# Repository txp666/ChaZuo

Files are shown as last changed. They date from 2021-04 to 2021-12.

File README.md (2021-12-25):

# 智能插座2.0

半年前设计的智能插座，只完成一半，由于来了学校以后只能使用校园网，设备连接后需要登陆，所以一直没用这个插座，就扔墙角吃灰了。前几天想起来更新2.0。

## 1.  背景

Esp8266刷入HomeKit后，苹果手机可以在家庭APP中进行控制，但是如果没有ipad或homepod则只可以在局域网内使用，无法远程控制。

## 2.  解决方案

  使用两片esp8266，一片接入HomeKit一片接入阿里云。

## 3.  原理图

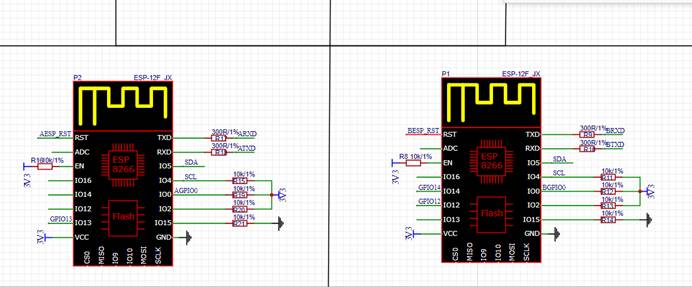
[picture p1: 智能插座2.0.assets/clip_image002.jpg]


两个芯片设置io4、io5进行软串口通讯

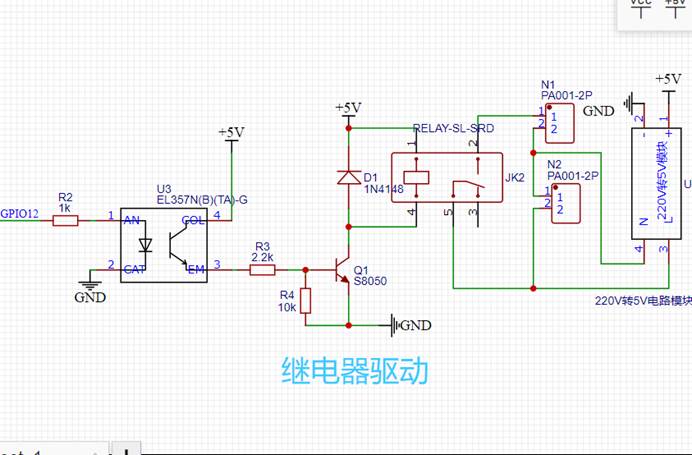
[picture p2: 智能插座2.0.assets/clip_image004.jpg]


Io12控制继电器

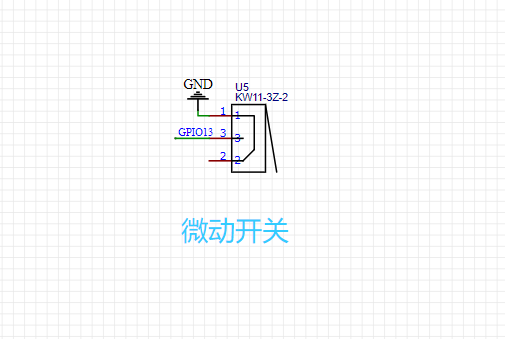
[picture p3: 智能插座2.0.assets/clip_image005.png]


Io13连接微动开关

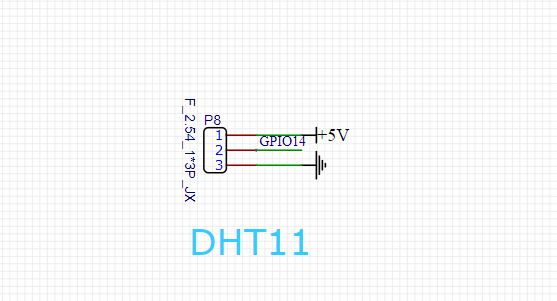
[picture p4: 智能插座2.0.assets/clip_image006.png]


可以添加温湿度传感器

## 4.  PCB

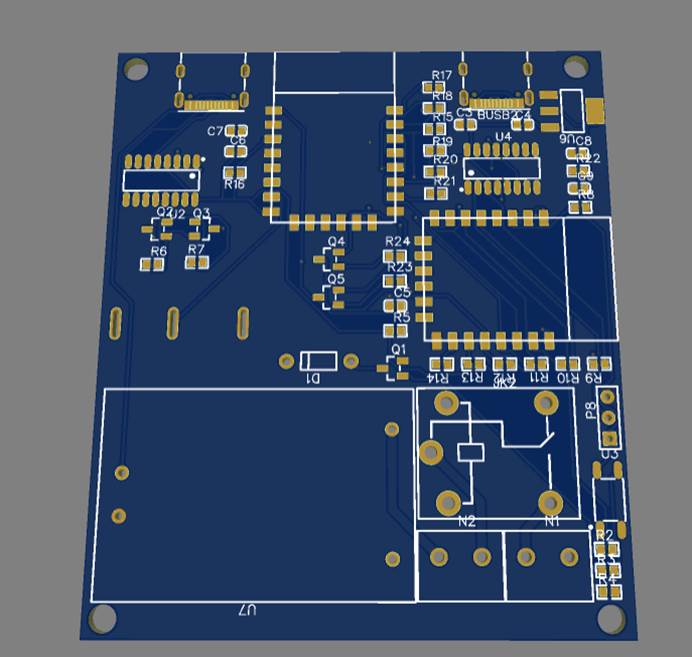
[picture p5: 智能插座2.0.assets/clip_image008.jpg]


使用了两个type-c接口分别对两个芯片下载程序

左边的刷阿里云的程序，右面的刷HomeKit。

## 5.  阿里云配置

进入阿里云物联网平台新建一个公共实例

https://iot.console.aliyun.com

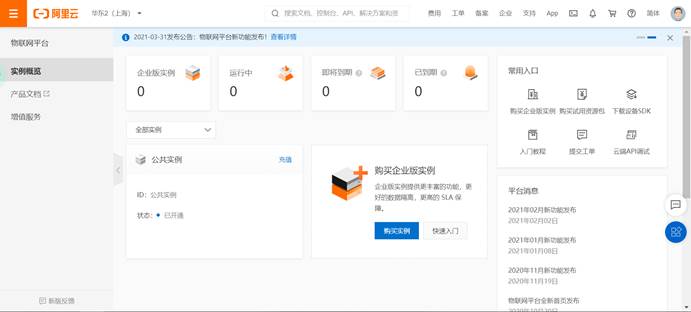
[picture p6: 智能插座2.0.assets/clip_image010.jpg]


创建一个产品

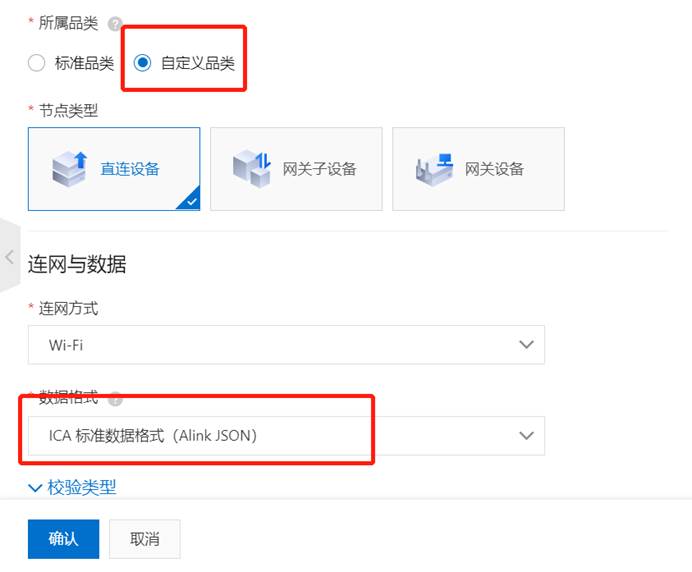
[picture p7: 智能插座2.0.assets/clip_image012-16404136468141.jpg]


添加一个设备

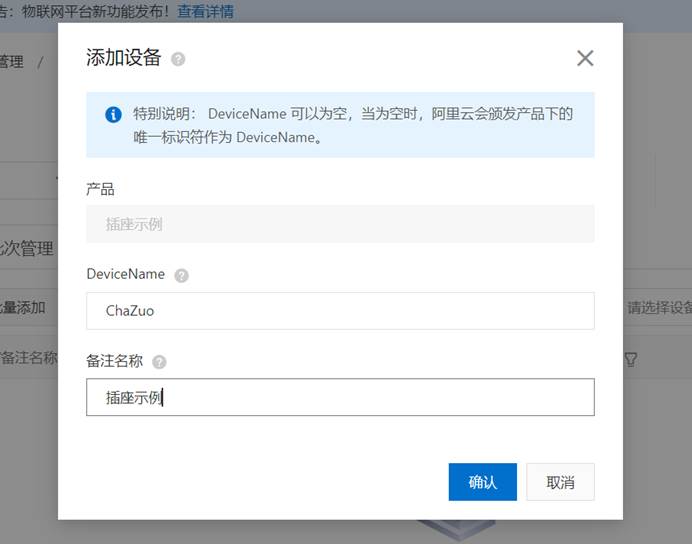
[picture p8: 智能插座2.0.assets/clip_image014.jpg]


回到产品，功能定义，编辑草稿

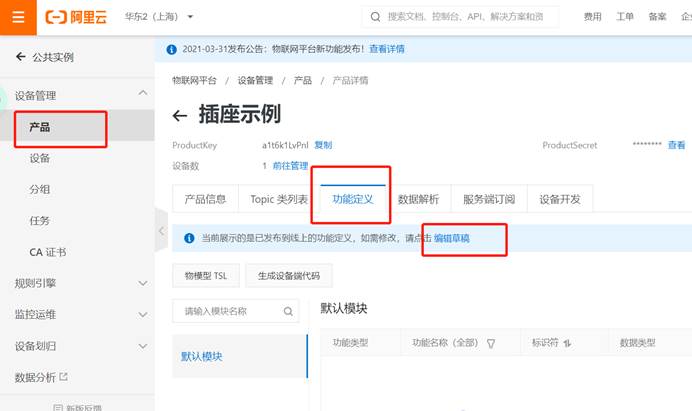
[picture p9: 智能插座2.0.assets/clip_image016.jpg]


添加一个自定义功能

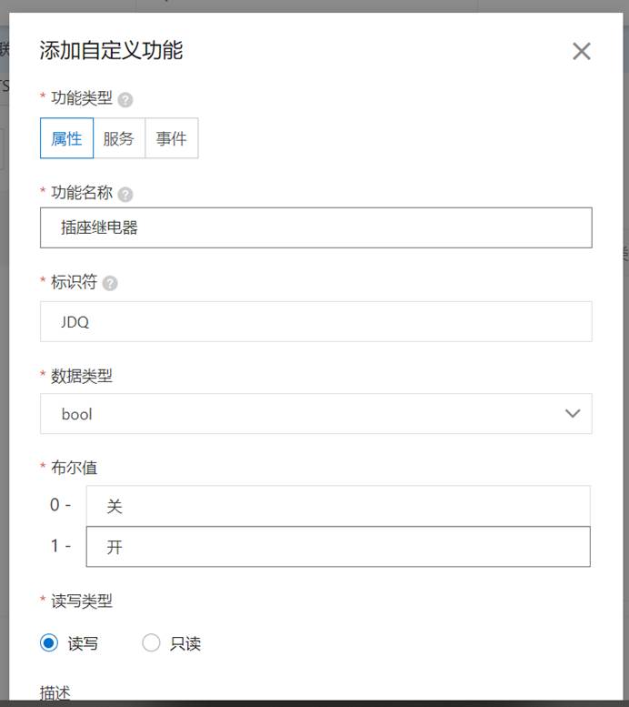
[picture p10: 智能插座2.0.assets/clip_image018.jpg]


发布上线

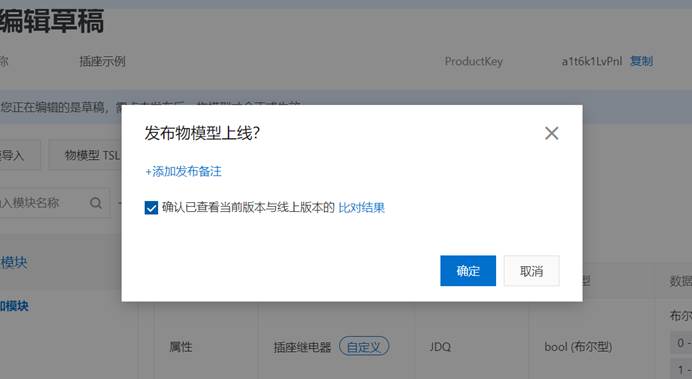
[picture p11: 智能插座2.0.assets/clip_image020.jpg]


## 6.  阿里云程序

这里用的Arduino环境写8266程序

环境搭建自行搜索

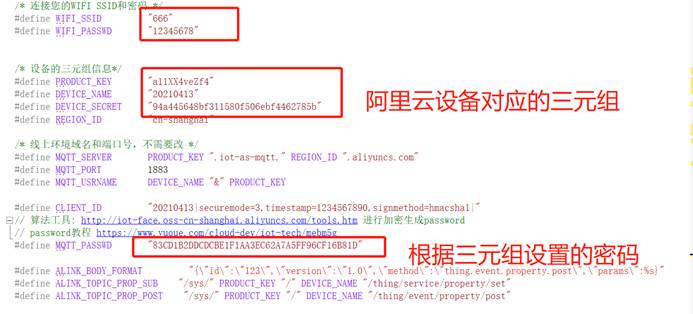
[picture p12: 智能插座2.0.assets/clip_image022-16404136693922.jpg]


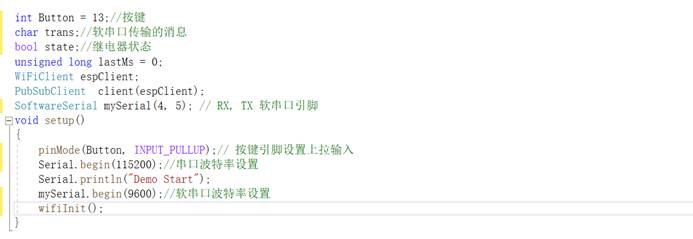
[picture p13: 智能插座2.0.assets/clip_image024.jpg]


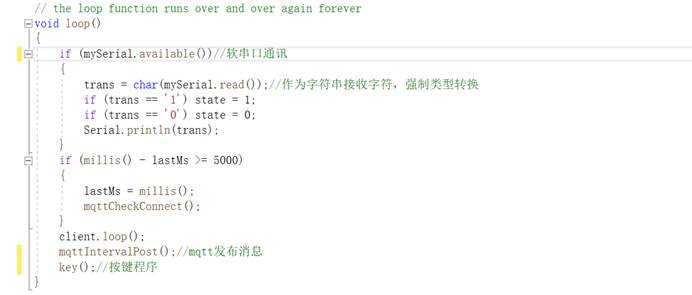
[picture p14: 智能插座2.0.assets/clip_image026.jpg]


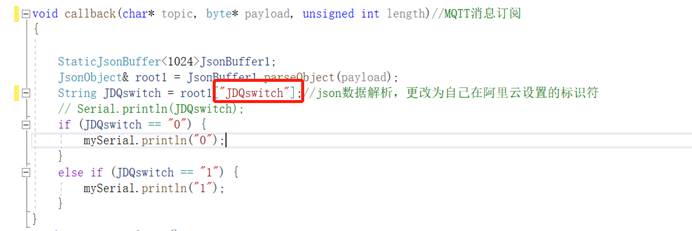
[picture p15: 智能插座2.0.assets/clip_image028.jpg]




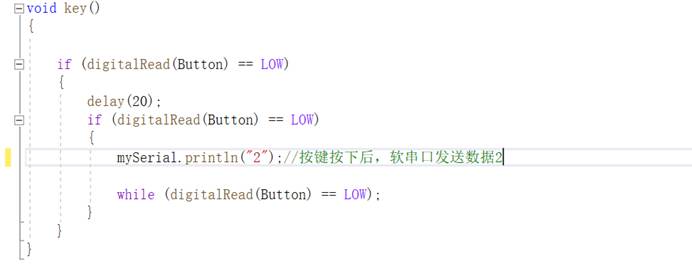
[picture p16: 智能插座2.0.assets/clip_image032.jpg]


## 7.  HomeKit程序

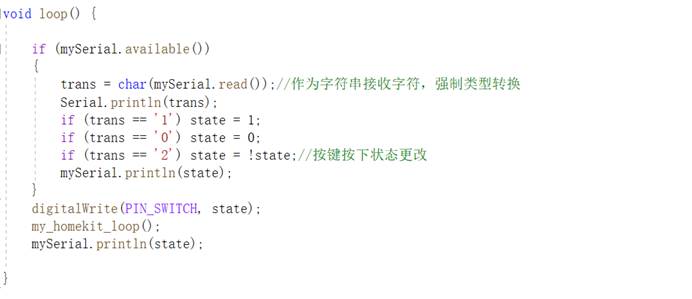
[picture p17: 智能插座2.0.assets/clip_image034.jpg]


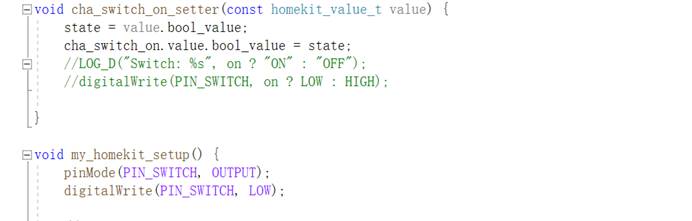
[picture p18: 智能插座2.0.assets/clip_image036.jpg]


特别注意一下，json库要使用V5版本

Pubsubclient.h也要修改

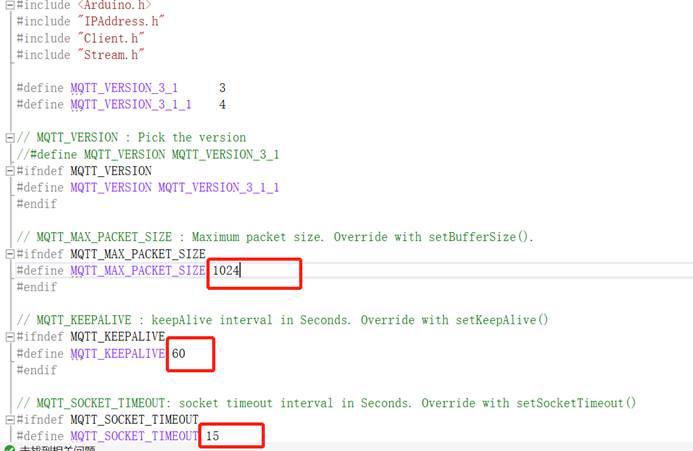
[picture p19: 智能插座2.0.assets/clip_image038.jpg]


## 8.  微信小程序

首先在新建的产品里新建一个设备，对应微信小程序

打开微信开发者工具，打开下载的程序（开发小程序，微信公众平台要进行设置，自行搜索）

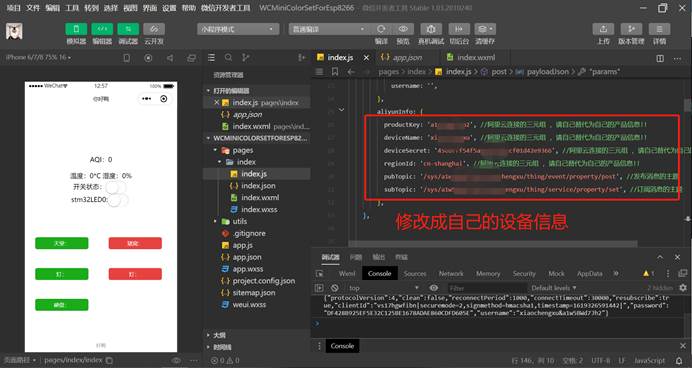
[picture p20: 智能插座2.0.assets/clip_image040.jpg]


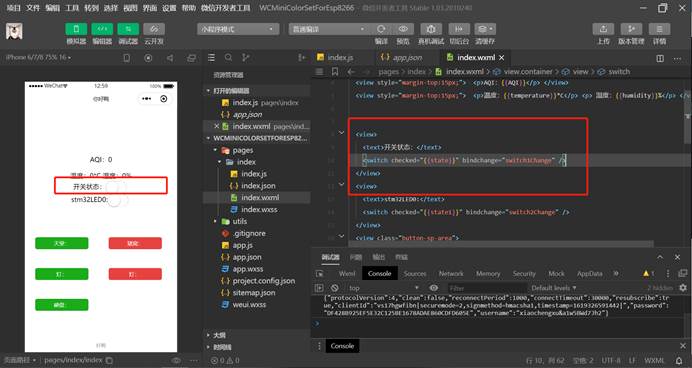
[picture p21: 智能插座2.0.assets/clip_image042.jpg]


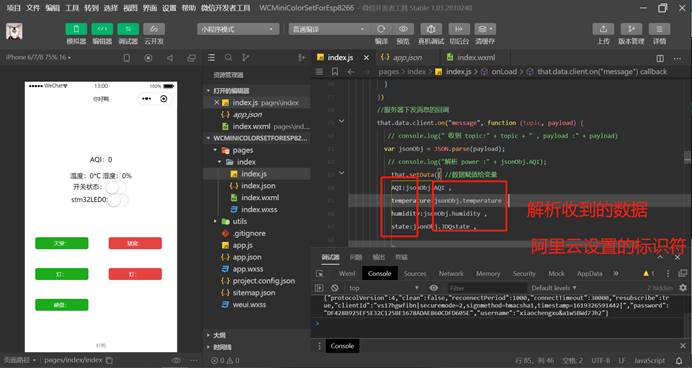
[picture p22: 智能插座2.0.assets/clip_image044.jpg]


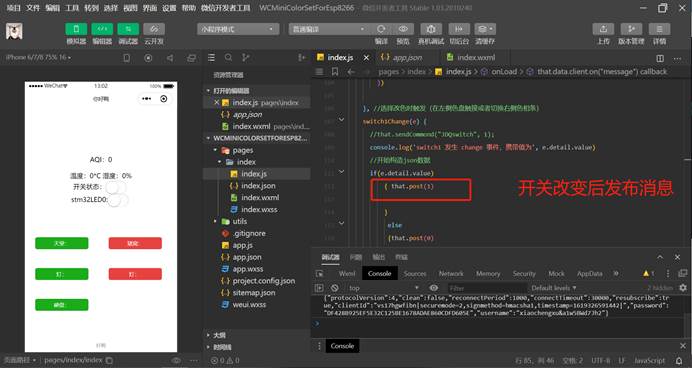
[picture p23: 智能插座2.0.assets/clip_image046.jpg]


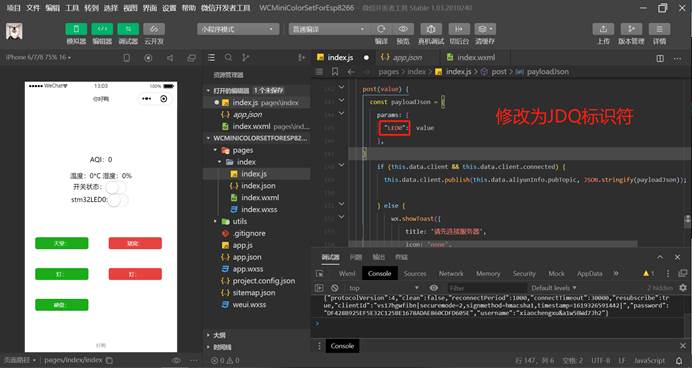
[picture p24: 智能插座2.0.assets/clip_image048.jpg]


阿里云设置数据流转，将小程序推送的消息转发到插座

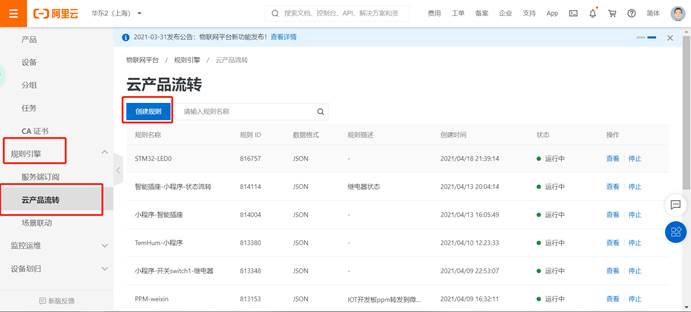
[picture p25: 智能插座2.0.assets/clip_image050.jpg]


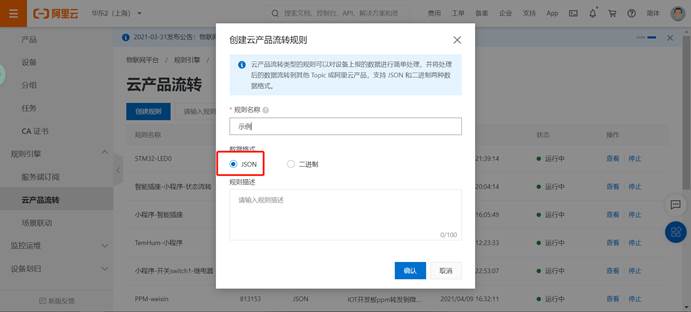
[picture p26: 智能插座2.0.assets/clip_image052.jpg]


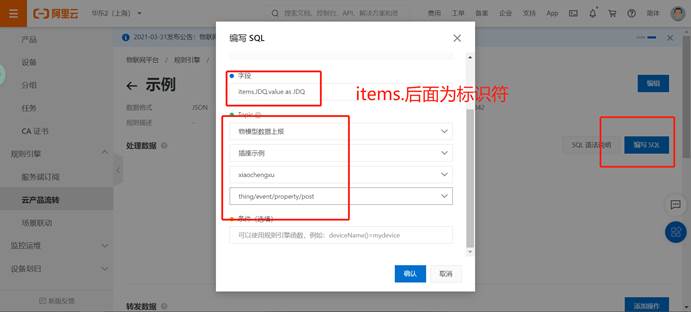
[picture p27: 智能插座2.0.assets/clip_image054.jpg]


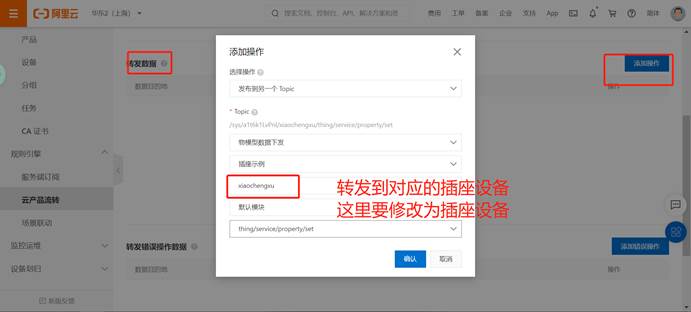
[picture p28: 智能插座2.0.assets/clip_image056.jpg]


返回去启动规则

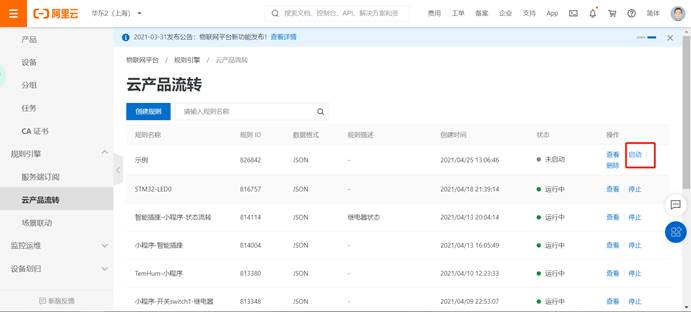
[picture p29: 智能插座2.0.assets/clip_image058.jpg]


完成后就可以使用小程序控制插座了，插座状态上传是一样的，建立规则把小程序状态流转到小程序

## 9.  HomeKit设置

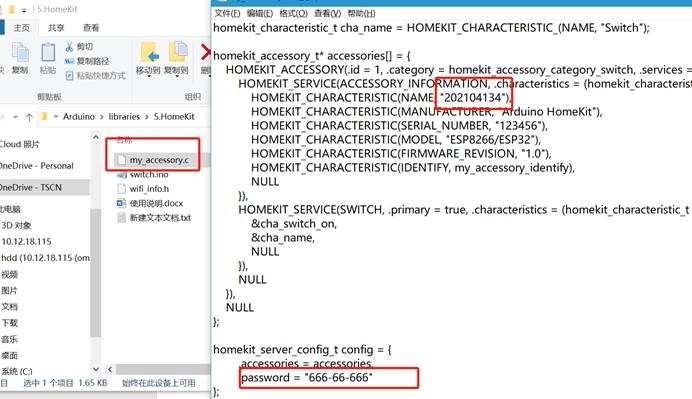
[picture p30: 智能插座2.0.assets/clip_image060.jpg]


名字时刷入flash ，所以如果在已经刷过homeKit程序的8266，需要清除flash信息（自行搜索）否则app里找不到设备

刷入程序后添加设备，点我没有或无法扫描，之后会弹出设备，输入上面设置的密码，之后按提示操作，HomeKit操作要在一个局域网内。

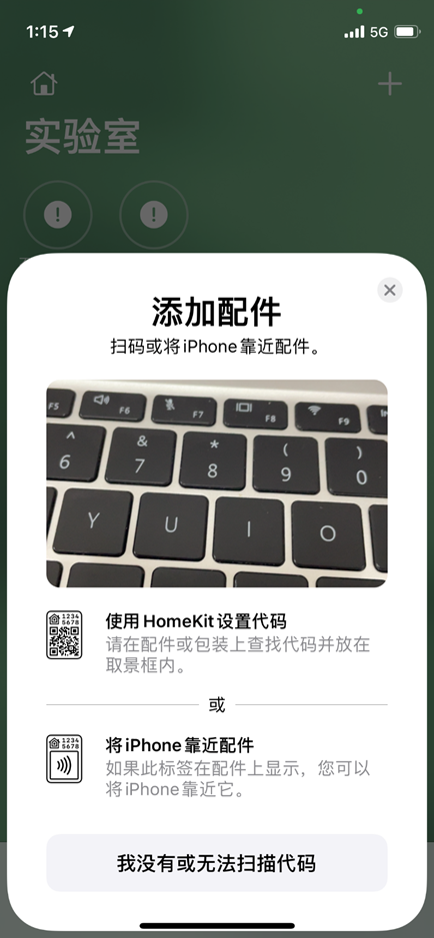
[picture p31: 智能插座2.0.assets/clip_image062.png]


完成之后就可以在家庭app和小程序同时进行控制了。

完成后实物

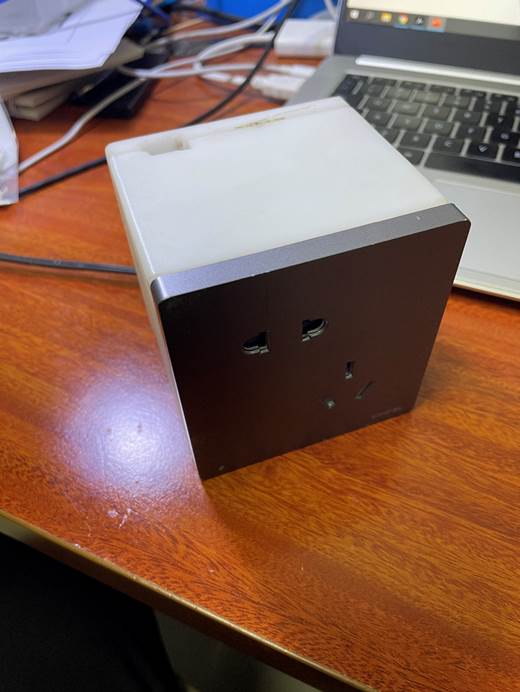
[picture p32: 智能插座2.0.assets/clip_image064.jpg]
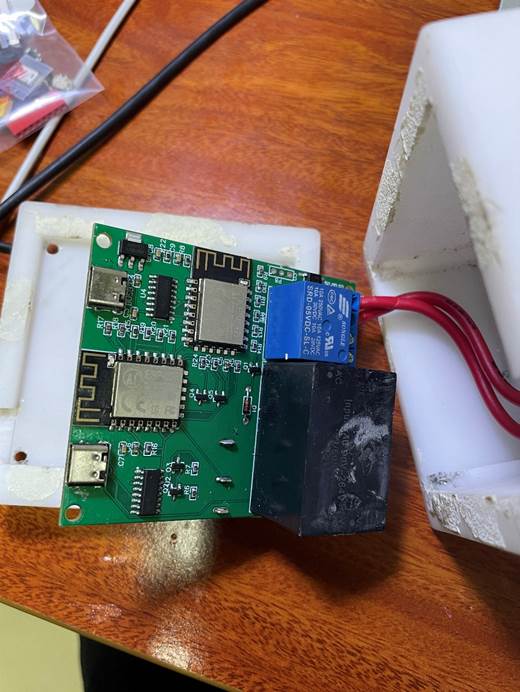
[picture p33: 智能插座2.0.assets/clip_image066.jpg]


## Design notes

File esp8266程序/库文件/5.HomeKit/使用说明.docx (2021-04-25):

第一步：打开switch.ino文件，在项目-加载库-管理库 安装homekit库

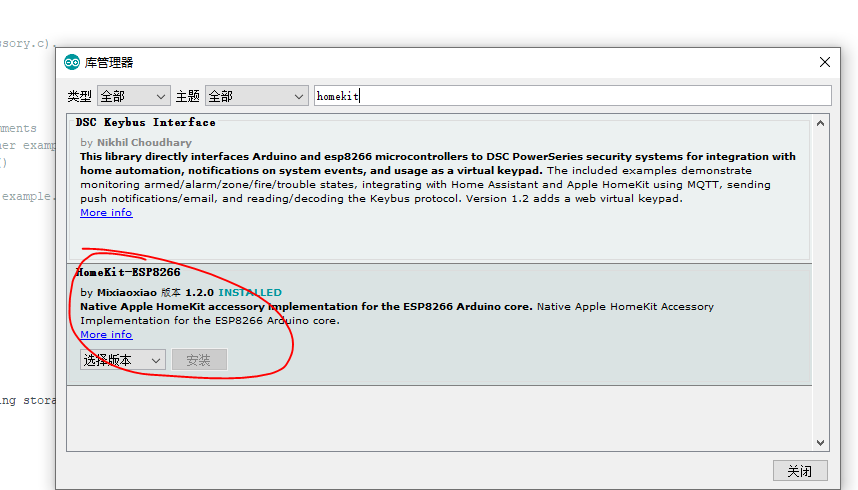
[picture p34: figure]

第二步：填写自己的WIFI

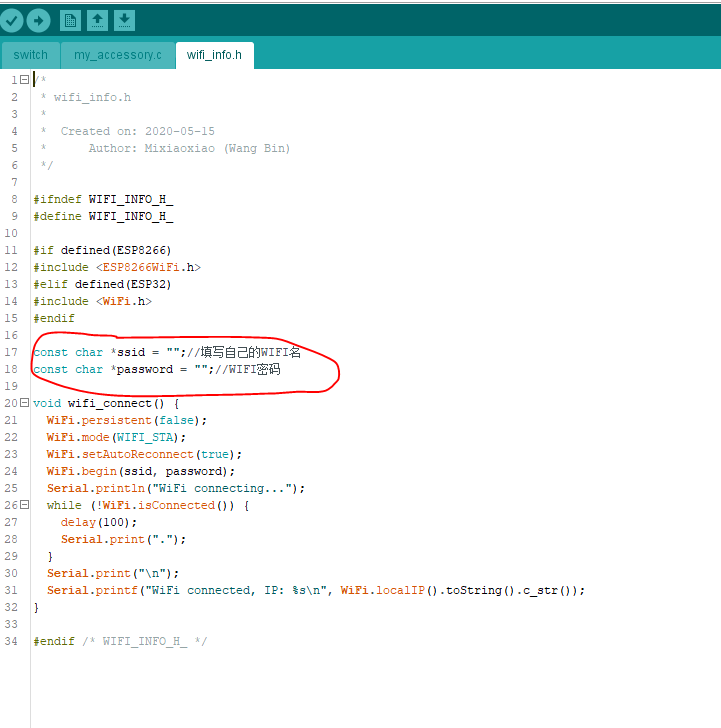
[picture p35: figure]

第三步：修改Homekit密码，可以不修改保持默认。苹果homekit app添加硬件时要输入。

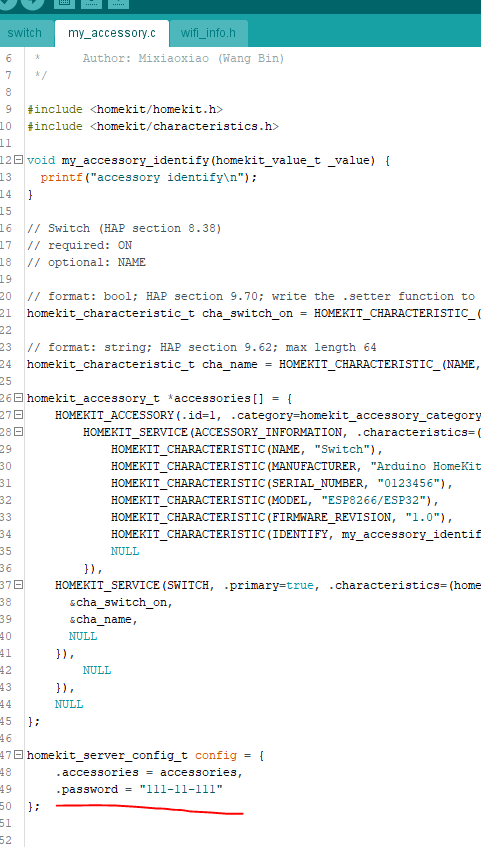
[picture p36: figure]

第四步：填写自己硬件控制的IO

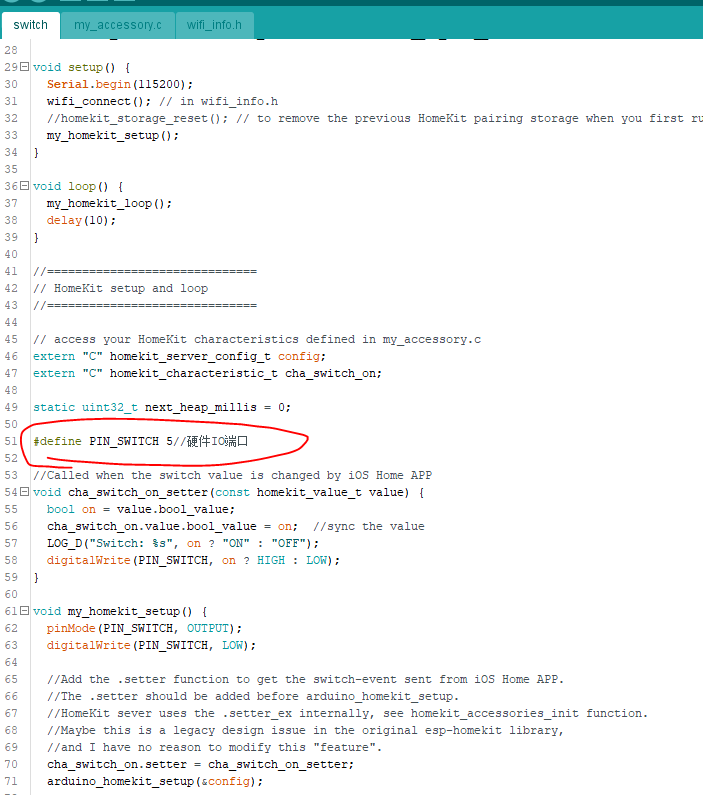
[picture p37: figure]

第五步：编译烧录

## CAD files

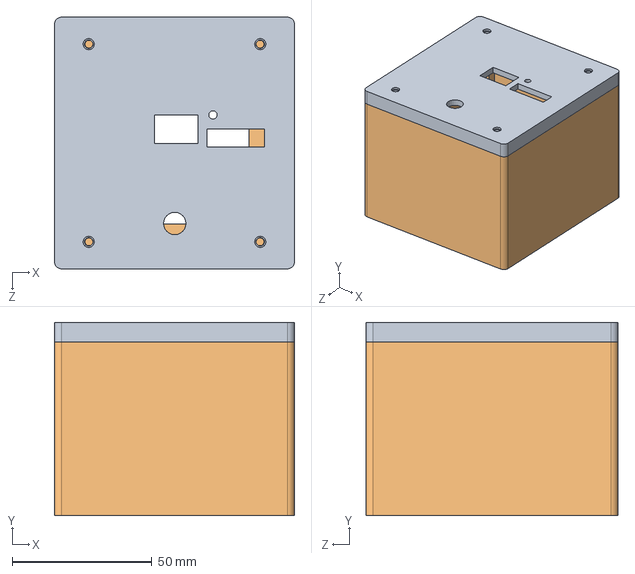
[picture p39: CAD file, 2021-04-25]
3D文件（未修改）请自行优化，修改/插座装配体.SLDASM
85.8 x 69.0 x 90.0 mm
插座后盖
插座壳体

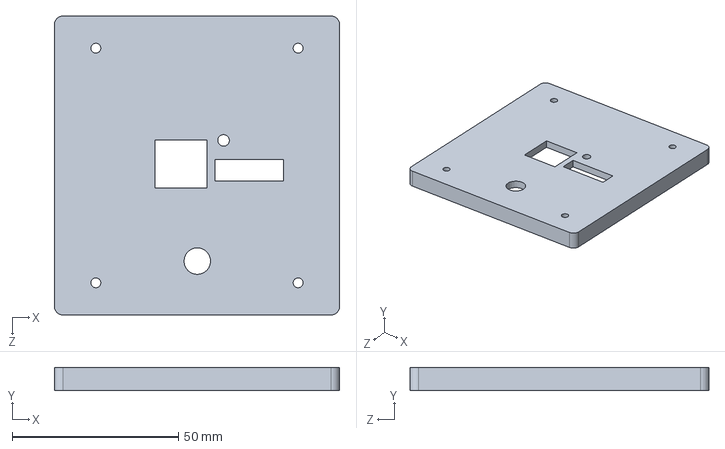
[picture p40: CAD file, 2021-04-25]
3D文件（未修改）请自行优化，修改/插座后盖.SLDPRT
85.8 x 7.00 x 90.0 mm

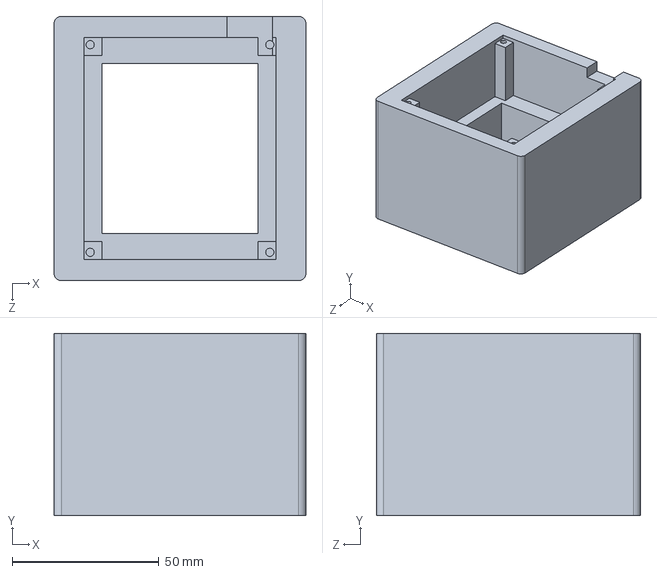
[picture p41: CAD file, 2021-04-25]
3D文件（未修改）请自行优化，修改/插座壳体.SLDPRT
85.8 x 62.0 x 90.0 mm

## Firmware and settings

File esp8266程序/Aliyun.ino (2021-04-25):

#include <ESP8266WiFi.h>
/* 依赖 PubSubClient 2.4.0 */
#include <PubSubClient.h>
/* 依赖 ArduinoJson 5.13.4 */
#include <ArduinoJson.h>
#include <SoftwareSerial.h>



/* 连接您的WIFI SSID和密码 */
#define WIFI_SSID         "666"
#define WIFI_PASSWD       "12345678"


/* 设备的三元组信息*/
#define PRODUCT_KEY       "" 
#define DEVICE_NAME       ""
#define DEVICE_SECRET     ""
#define REGION_ID         "cn-shanghai"

/* 线上环境域名和端口号，不需要改 */
#define MQTT_SERVER       PRODUCT_KEY ".iot-as-mqtt." REGION_ID ".aliyuncs.com"
#define MQTT_PORT         1883
#define MQTT_USRNAME      DEVICE_NAME "&" PRODUCT_KEY

#define CLIENT_ID         "20210413|securemode=3,timestamp=1234567890,signmethod=hmacsha1|"
// 算法工具: http://iot-face.oss-cn-shanghai.aliyuncs.com/tools.htm 进行加密生成password
// password教程 https://www.yuque.com/cloud-dev/iot-tech/mebm5g
#define MQTT_PASSWD       ""

#define ALINK_BODY_FORMAT         "{\"id\":\"123\",\"version\":\"1.0\",\"method\":\"thing.event.property.post\",\"params\":%s}"
#define ALINK_TOPIC_PROP_SUB    "/sys/" PRODUCT_KEY "/" DEVICE_NAME "/thing/service/property/set"
#define ALINK_TOPIC_PROP_POST    "/sys/" PRODUCT_KEY "/" DEVICE_NAME "/thing/event/property/post"

int Button = 13;//按键
char trans;//软串口传输的消息
bool state;//继电器状态
unsigned long lastMs = 0;
WiFiClient espClient;
PubSubClient  client(espClient);
SoftwareSerial mySerial(4, 5); // RX, TX 软串口引脚
void setup()
{
    pinMode(Button, INPUT_PULLUP);// 按键引脚设置上拉输入
    Serial.begin(115200);//串口波特率设置
    Serial.println("Demo Start");
    mySerial.begin(9600);//软串口波特率设置
    wifiInit();
}


// the loop function runs over and over again forever
void loop()
{
    if (mySerial.available())//软串口通讯
    {
        trans = char(mySerial.read());//作为字符串接收字符，强制类型转换
        if (trans == '1') state = 1;
        if (trans == '0') state = 0;
        Serial.println(trans);
    }
    if (millis() - lastMs >= 5000)
    {
        lastMs = millis();
        mqttCheckConnect();
    }
    client.loop();
    mqttIntervalPost();//mqtt发布消息
    key();//按键程序
}

void callback(char* topic, byte* payload, unsigned int length)//MQTT消息订阅
{
   
    StaticJsonBuffer<1024>JsonBuffer1;
    JsonObject& root1 = JsonBuffer1.parseObject(payload);
    String JDQ = root1["JDQ"];//json数据解析，更改为自己在阿里云设置的标识符
    // Serial.println(JDQswitch);
    if (JDQ == "0") {
        mySerial.println("0");
    }
    else if (JDQ == "1") {
        mySerial.println("1");
    }
}
void mqttIntervalPost()
{
    char param[32];
    char jsonBuf[128];
    sprintf(param, "{\"JDQstate\":%d}",state);//向标识符JDQstate发布当前的开关状态
    sprintf(jsonBuf, ALINK_BODY_FORMAT, param);
    boolean d = client.publish(ALINK_TOPIC_PROP_POST, jsonBuf);
}
void wifiInit()
{
    WiFi.mode(WIFI_STA);
    WiFi.begin(WIFI_SSID, WIFI_PASSWD);
    while (WiFi.status() != WL_CONNECTED)
    {
        delay(1000);
        Serial.println("WiFi not Connect");
    }

    Serial.println("Connected to AP");
    Serial.println("IP address: ");
    Serial.println(WiFi.localIP());


    Serial.print("espClient [");


    client.setServer(MQTT_SERVER, MQTT_PORT);   /* 连接WiFi之后，连接MQTT服务器 */
    client.setCallback(callback);

}
void mqttCheckConnect()
{
    while (!client.connected())
    {
        Serial.println("Connecting to MQTT Server ...");
        if (client.connect(CLIENT_ID, MQTT_USRNAME, MQTT_PASSWD))

        {
            Serial.println("MQTT Connected!");
            client.subscribe(ALINK_TOPIC_PROP_SUB);

        }
        else
        {
            Serial.print("MQTT Connect err:");
            Serial.println(client.state());
            delay(5000);
        }
    }
}
void key()
{
   
    if (digitalRead(Button) == LOW)
    {
        delay(20);
        if (digitalRead(Button) == LOW)
        {
            mySerial.println("2");//按键按下后，软串口发送数据2
            
            while (digitalRead(Button) == LOW);
        }
    }
}

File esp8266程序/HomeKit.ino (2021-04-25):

// Visual Micro is in vMicro>General>Tutorial Mode
// 
/*
    Name:       HomeKit.ino
    Created:	2021/4/3 19:20:46
    Author:     DESKTOP-C3QC8JH\txp
*/

// Define User Types below here or use a .h file
//


// Define Function Prototypes that use User Types below here or use a .h file
//


// Define Functions below here or use other .ino or cpp files
//

// The setup() function runs once each time the micro-controller starts


#include <Arduino.h>
#include <arduino_homekit_server.h>
#include "wifi_info.h"
#include <SoftwareSerial.h>


SoftwareSerial mySerial(5, 4); // RX, TX软串口
char trans;
bool* a;
bool state=&a;
#define LOG_D(fmt, ...)   printf_P(PSTR(fmt "\n") , ##__VA_ARGS__);
#define PIN_SWITCH 12//继电器引脚
void setup() {
	Serial.begin(115200);
	mySerial.begin(9600);
	wifi_connect(); // in wifi_info.h
	//homekit_storage_reset(); // to remove the previous HomeKit pairing storage when you first run this new HomeKit example
	my_homekit_setup();

}

void loop() {

	if (mySerial.available())
	{
		trans = char(mySerial.read());//作为字符串接收字符，强制类型转换
		Serial.println(trans);	
		if (trans == '1') state = 1; 
		if (trans == '0') state = 0;
		if (trans == '2') state = !state;//按键按下状态更改
		mySerial.println(state);
	}
	digitalWrite(PIN_SWITCH, state);
	my_homekit_loop();
	mySerial.println(state);
	
}

//==============================
// HomeKit setup and loop
//==============================

// access your HomeKit characteristics defined in my_accessory.c
extern "C" homekit_server_config_t config;
extern "C" homekit_characteristic_t cha_switch_on;

static uint32_t next_heap_millis = 0;



//Called when the switch value is changed by iOS Home APP
void cha_switch_on_setter(const homekit_value_t value) {
	state = value.bool_value;
	cha_switch_on.value.bool_value = state;	
	//LOG_D("Switch: %s", on ? "ON" : "OFF");
	//digitalWrite(PIN_SWITCH, on ? LOW : HIGH);	
	
}

void my_homekit_setup() {
	pinMode(PIN_SWITCH, OUTPUT);
	digitalWrite(PIN_SWITCH, LOW);

	//Add the .setter function to get the switch-event sent from iOS Home APP.
	//The .setter should be added before arduino_homekit_setup.
	//HomeKit sever uses the .setter_ex internally, see homekit_accessories_init function.
	//Maybe this is a legacy design issue in the original esp-homekit library,
	//and I have no reason to modify this "feature".
	cha_switch_on.setter = cha_switch_on_setter;
	arduino_homekit_setup(&config);

	//report the switch value to HomeKit if it is changed (e.g. by a physical button)
	//bool switch_is_on = true/false;
	//cha_switch_on.value.bool_value = switch_is_on;
	//homekit_characteristic_notify(&cha_switch_on, cha_switch_on.value);
}

void my_homekit_loop() {
	arduino_homekit_loop();
	const uint32_t t = millis();
	if (t > next_heap_millis) {
		// show heap info every 5 seconds
		next_heap_millis = t + 5 * 10;
		LOG_D("Free heap: %d, HomeKit clients: %d",
			ESP.getFreeHeap(), arduino_homekit_connected_clients_count());

	}
}

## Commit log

2021-04-25 Create 新建 Microsoft Word 文档.docx
2021-04-25 三元组更改
2021-12-25 删除 Visual Micro 20.09.10.2.exe
2021-12-25 添加readme
2021-12-25 修改readme
